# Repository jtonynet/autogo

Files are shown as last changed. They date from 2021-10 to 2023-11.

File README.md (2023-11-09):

### Raspberry Pi Autonomous Golang 1.16 robot

<!-- 
    Logo image generated by Bing IA: https://www.bing.com/images/create/
-->
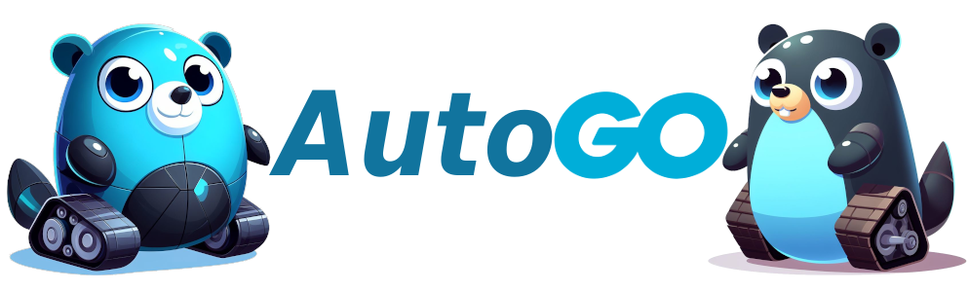
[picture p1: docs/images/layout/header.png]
CineCataloGO, Study RESTful APIs in Golang for cinema catalog management CineCataloGO

__Refactor para Go 1.21 em andamento*__

<br/>

[go Go](https://go.dev/) [Javascript](https://developer.mozilla.org/en-US/docs/Web/JavaScript) [NodeJS](https://nodejs.org/en) [Ubunto](https://ubuntu.com/) [DotEnv](https://github.com/spf13/viper) [GitHub](https://github.com/jtonynet) [Miro](https://miro.com/) [Fritzing](https://fritzing.org/)  [VsCode](https://code.visualstudio.com/) [Heroku](https://heroku.com) [MQTT](https://mqtt.org/) [RaspberryPi](https://www.raspberrypi.org/) [Arduino](https://www.arduino.cc/) 

 

<br/>

#### 🕸️ Minhas Redes:
     

---

Projeto em desenvolvimento com finalidade de estudo de uso de Golang com Robotica Básica e IOT (libs [Gobot](https://gobot.io/) e [Gocv](https://gocv.io/)), funcional na plataforma base (Raspberry 3b+/4b Rasbpian recente).

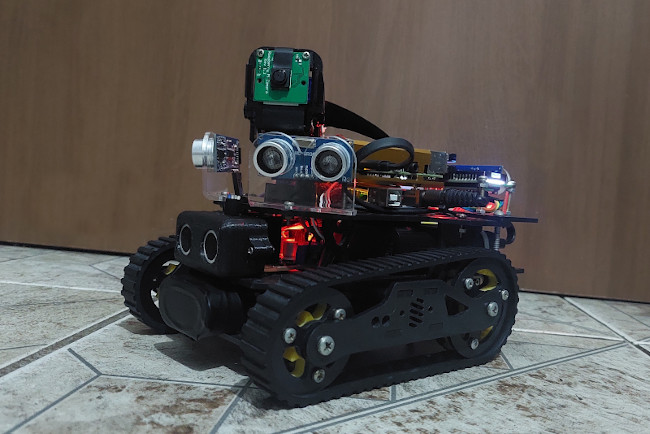
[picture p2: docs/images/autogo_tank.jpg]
versão atual montado


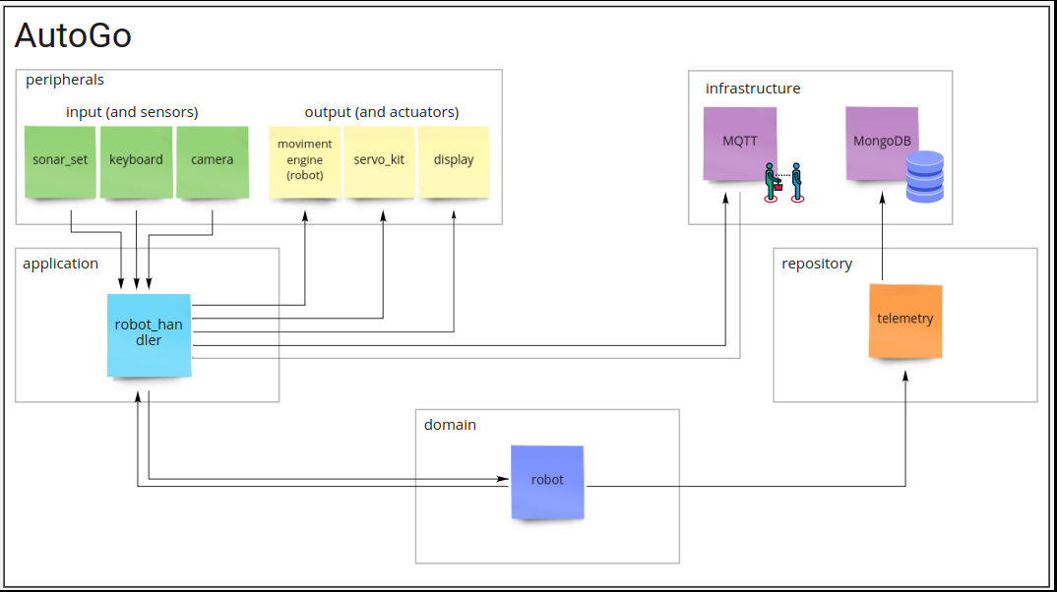
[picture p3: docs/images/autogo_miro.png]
arquitetura


Setup:
  1. Em uma plataforma raspberry que siga o esquema autoGo e seus [scripts auxiliares](./scripts/README.md), instalar o [pi-blaster](https://github.com/sarfata/pi-blaster)

  2. Rodar ´sudo raspi-config´ entrar em ´3 Interface Options´ para habilitar a interface de camera ´P1 Camera´ e o barramento ´P5 I2C´

  3. Rodar o comando para alterar pinagem i2c e habilitar todos pins para o gobot: `./autogo.sh`

  4. Gerando Binário com raspberry como device alvo: `GOARM=6 GOARCH=arm GOOS=linux go build main.go`

  5. Rode o Binário. Com um teclado conectado ao raspberry, teclas de seta movimentam o veiculo, teclas "a, w, s, d" movimentam os servos da camera. Stream de video, condução pela web (pagina cliente) e condução autônoma (via sensor de sonar e outros métodos) ainda serão implementados

Esquema autoGo
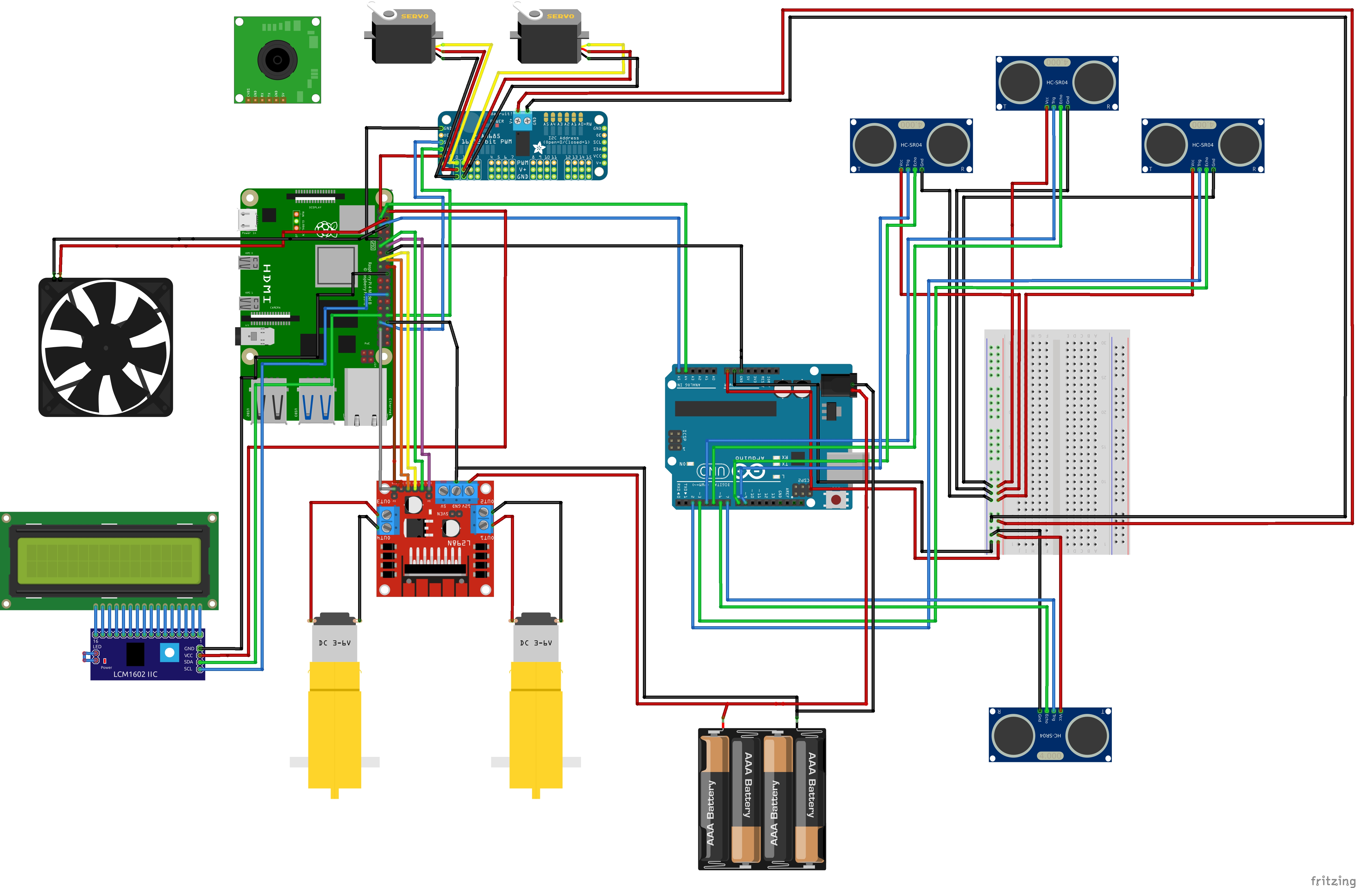
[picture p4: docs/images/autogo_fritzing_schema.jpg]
esquema


Setup Client:
  1. Configurar no arquivo .env o MessagerBroker com dados de uma conta MQTT. Broker [hive](https://www.hivemq.com/mqtt-cloud-broker/) gratuito sugerido
   
  2. Rodar `docker build --tag autogo-client-test .` e depois da imagem buildada rodar `docker run autogo-client-test`

  3. Validar mensagens de acordo com os recursos do autogo configurado na mesma fila com as mesmas envs `PROJECT_NAME` e `ROBOT_NAME`. Ter um client configurado no computador de testes é aconselhável, sugestão [mqtt-explorer](http://mqtt-explorer.com/)

Site Cliente e MQTT
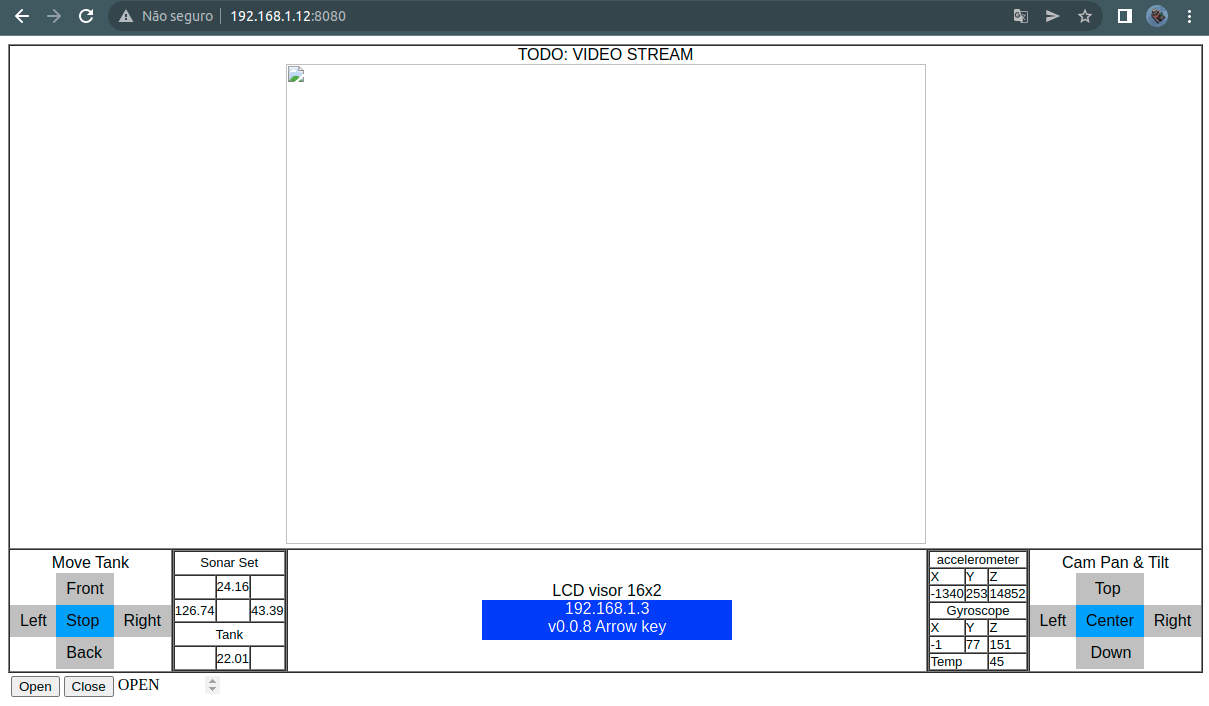
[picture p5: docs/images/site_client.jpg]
site cliente cliente


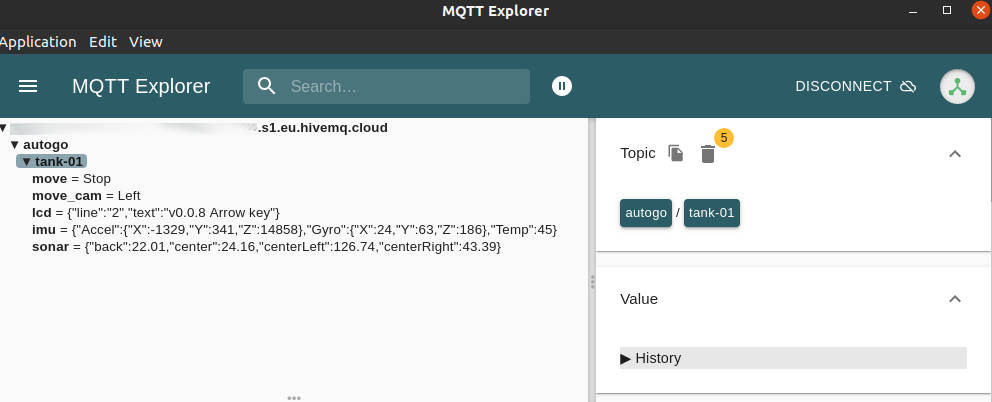
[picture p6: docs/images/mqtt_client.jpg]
app cliente cliente


Referências:
  - [Pq nao dockerizar o device?](https://ubuntu.com/blog/ros-docker)
  - [:::ROS Golang](https://ubuntu.com/blog/go-for-ros)
  - [Condução Autônoma IA com Intel 1](https://towardsdatascience.com/robot-tank-with-raspberry-pi-and-intel-neural-computer-stick-2-77263ca7a1c7)
  - [Go visão computacional](https://about.sourcegraph.com/go/gophercon-2018-computer-vision-using-go-and-opencv-3/)
  - [Raspberry com Gobot](https://gobot.io/documentation/platforms/raspi/)
  - [GPIO com Golang](https://pkg.go.dev/github.com/heupel/gobot/platforms/gpio#section-readme)
  - [Lib LCD i2c Golang](https://github.com/d2r2/go-hd44780)

-Próximas etapas:
  - ~~Refatoração na estrutura do código~~
  - ~~Condução Autônoma (Sonar set)~~
  - ~~Condução por Fila MQTT (e web Socket)~~
  - ~~Site Cliente para Condução~~
  - Dockerizar o site cliente e suas dependencias
  - Código mais aderente a boas práticas GO (interfaces, linter e demais melhorias)
  - SH e makefile para automatizar dependencias em instalação nova
  - SH update de goversion no raspbian
  - Testes e validação para outros SO, Ubunto Mate (raspberry 4b) e Ubunto Nvidia Jetson :)
  - Implantar ROS::: Golang

Componentes:
  - [Plataforma Rocket-tank](https://www.robocore.net/robotica-robocore/plataforma-robotica-rocket-tank)
  - [Kit de expansão Rocket-tank](https://www.robocore.net/item-mecanico/kit-de-expansao-rocket-tank)
  - [Suporte pan tilt](https://lista.mercadolivre.com.br/suporte-pan-tilt-arduino)
  - [PowerBank minimo 2,5 amperes](https://lista.mercadolivre.com.br/powerbank-mi#D[A:PowerBank%20mi])
  - [Bateria 7,2 V](https://lista.mercadolivre.com.br/bateria-leao-nimh-7.2#D[A:bateria%20leao%20nimh%207.2])
  - [Raspberry py ModelB 3 ou mais recente](https://lista.mercadolivre.com.br/raspberry-py-modelb-3)
  - [Case raspberry com fan](https://lista.mercadolivre.com.br/case-raspberry-pi-cooler-duplo-aluminio_OrderId_PRICE_NoIndex_True)
  - [Raspicam](https://www.robocore.net/acessorios-raspberry-pi/camera-para-raspberry-pi-rev-1-3)
  - [16 ch pwm](https://lista.mercadolivre.com.br/16-ch-pwm)
  - [2x servos motores 9g](https://lista.mercadolivre.com.br/servos-motores-9g#D[A:servos%20motores%209g])
  - [Ponte H l298n](https://lista.mercadolivre.com.br/raspiberry-cam)
  - [Display LCD 16x2 i2c](https://lista.mercadolivre.com.br/display-16x2-i2c#D[A:display%2016x2%20i2c])
  - [4x Sensores Sonar](https://lista.mercadolivre.com.br/arduino-sonar-sensores#D[A:arduino%20sonar%20sensores])
  - [Arduino UNO](https://lista.mercadolivre.com.br/arduino-uno#D[A:Arduino%20UNO])
  - [Mini teclado sem fio](https://lista.mercadolivre.com.br/mini-keyboard#D[A:mini%20keyboard])
  - [Parafusos e porcas M3 20mm e 12mm](https://lista.mercadolivre.com.br/parafusos-e-porcas-m3-20mm#D[A:Parafusos%20e%20porcas%20M3%2020mm])
  - [Conector p4 2.1 mm](https://lista.mercadolivre.com.br/conector-p4-2.1-mm#D[A:conector%20p4%202.1%20mm])
  - [MPU9250](https://lista.mercadolivre.com.br/mpu9250#D[A:MPU9250])
  - MiniProtoboard OU Tubos termo retrateis, Cabos, fita isolante, curiosidade vontade e disposição para nao se frustrar muito no processo (o que não raro, vai acontecer)

Criando novas Issues. A ideia é manter atualizado enquanto avanço em Golang e outros tópicos vinculados interessantes.

Existe uma versão do projeto em Python (Autobot), pretendo andar com ela em paralelo pois Python já possui soluções que serão portadas para o AutoGo.

Um estudo divertido.
Todos estamos tentando melhorar. ;)

primeiro teste

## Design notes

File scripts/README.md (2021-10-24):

Scripts e códigos auxiliares para rodar o AutoGo (migrar para outro projeto no futuro)

  1. Baixar o [arduino](https://www.arduino.cc/) e subir o sketch (arquivo) do SonarSet no Arduino uno utilizado no AutoGo (em próximas versões o sketch será em golang e não mais um INO)

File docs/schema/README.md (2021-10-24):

[Baixar o fritzing](https://fritzing.org/download/) Para ter acesso e poder alterar o esquema de pinagem utilizado no AutoGo

Componentes que podem faltar na instalacao base do fritzing e outros exemplos:

  -  [Adafruit (pca9685)](https://github.com/adafruit/Fritzing-Library)
  -  [HC-SR04](https://github.com/RafaGS/Fritzing/blob/master/HC-SR04.fzpz)
  -  [L298N](https://forum.fritzing.org/t/h-bridge-with-l298n-motor-driver/7711/2)
  -  [i2c-lcd](https://fritzing.org/projects/arduino-i2c-lcd-display)
  -  [Servo](https://fritzing.org/projects/scratchx-servo-motor)
  -  [Fan](https://fritzing.org/projects/greenhouse-2)

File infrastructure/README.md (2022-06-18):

###MQTT tbm deve ir para um SH... talvez esse faça sentido Dockerizar

- [Instalação MQTT](https://www.instructables.com/Installing-MQTT-BrokerMosquitto-on-Raspberry-Pi/)

- [Boas práticas MQTT Amazon](https://docs.aws.amazon.com/whitepapers/latest/designing-mqtt-topics-aws-iot-core/mqtt-design-best-practices.html) e [Boas práticas MQTT Gerais](https://github.com/mqtt/mqtt.org/wiki/SYS-Topics)

- [Ferramenta MQTT](https://mqtt-explorer.com/)

- [Página de testes](https://test.mosquitto.org/)

- [Notas de instalação e resolução de problemas](https://github.com/eclipse/mosquitto/issues/529)

cd ~/etc/apt/sources.list.d
sudo -i

```
sharatkanthi commented on Apr 16, 2018
This is because the web socket library is not installed. Try running

sudo apt-get install libwebsockets-dev

before running

sudo apt-get install mosquitto
```

- [Problema de duplicidade, tenta subir o server MQTT duas vezes na porta 1883][http://www.steves-internet-guide.com/mosquitto-broker/]
```
mosquitto -V
sudo service mosquitto stop
sudo systemctl stop mosquitto.service
fuser -k 1883/tcp
mosquitto -V
```

- Testando (com 3 janelas distintas)
```
mosquitto

mosquitto_sub -h 0.0.0.0 -p 1883 -t 'autogo-test'

mosquitto_pub -h 0.0.0.0 -p 1883 -t 'autogo-test' -m 'test 3'
```

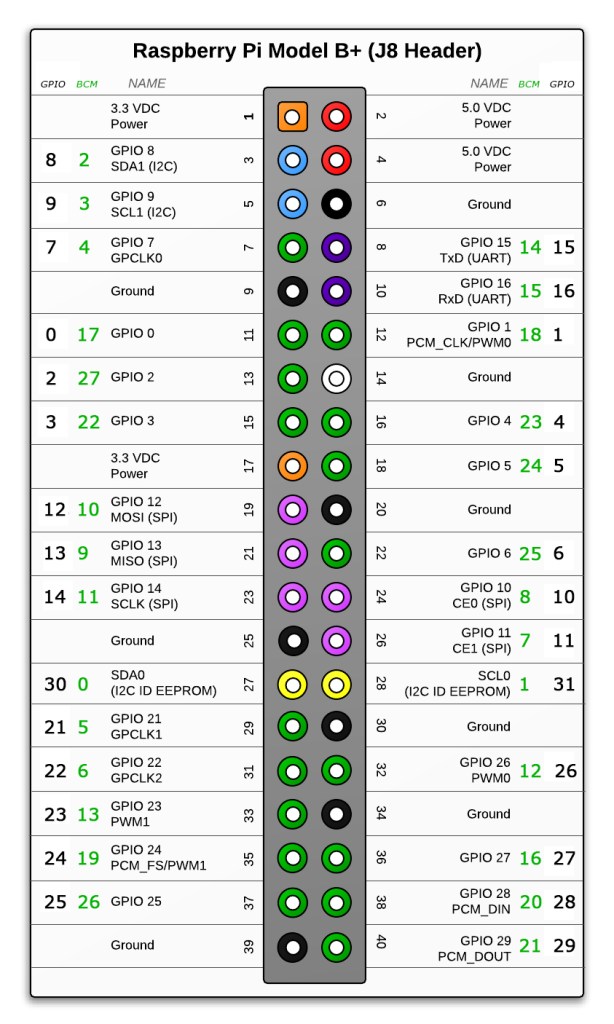
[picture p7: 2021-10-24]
docs/images/raspi_pins.jpg

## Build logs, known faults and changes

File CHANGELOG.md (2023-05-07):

# Changelog

All notable changes to this project will be documented in this file.

The format is based on [Keep a Changelog](https://keepachangelog.com/en/1.0.0/),
and this project adheres to [Semantic Versioning](https://semver.org/spec/v2.0.0.html).

## [Unreleased]
### Added 

## [0.0.8] - 2022-06-18
### Changed 
- Usando fila gratuita [hive](https://www.hivemq.com/mqtt-cloud-broker/) para mensageria MQTT ao invés de Mosquitto local
- Peripherals inputs e outputs renomeado para sensor e actuators
- Mais alguns arquivos renomeados para melhorar a clareza do código
  
### Added
- Site cliente adicionado com receita docker, funcional via MQTT e Websocket
- Comunicação entre site cliente e autogo implementada
- Sensor IMU "MPU9250" adicionado em actuators e domain, enviando dados para fila

## [0.0.7] - 2021-11-11

### Added 
- [Instalação Mosquito MQTT](https://www.instructables.com/Installing-MQTT-BrokerMosquitto-on-Raspberry-Pi/) mais um processo para automatizar (esse talvez possa deixar em docker)
- Criada Infrastructure MQTT seguindo [EMQ](https://www.emqx.com/en/blog/how-to-use-mqtt-in-golang), [AWS](https://docs.aws.amazon.com/pt_br/whitepapers/latest/designing-mqtt-topics-aws-iot-core/mqtt-design-best-practices.html) e [Hive MQTT](https://www-hivemq-com.translate.goog/blog/mqtt-essentials-part-4-mqtt-publish-subscribe-unsubscribe/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)
- Domain robotAggregator refactor para Responsabilidade unica de metodos
- Domain para LCD e Sonar com logica de mensageria
- EnvVars e mais alguns outros fixes

## [0.0.6] - 2021-11-02

### Added

- [Instalação Gocv](https://gocv.io/getting-started/linux/)
- Adicionando uso simples de [Gocv](https://github.com/willmendil/golang_tutorials/blob/master/tutorial_1/main.go)/OpenCv para video stream
- Display LCD na linha 1 exibe ip e porta de rede da camera caso online)
- Env vars de uso da camera
- Acertos no keyboard e Wrapper de keyevent (ainda não está 100%)

## [0.0.5] - 2021-10-30

### Added

- Perifericos (sensors/actuators) podem ser habilitados por envVars
    - Montagem minima apenas com motores (ou qualquer outra combinação) agora pode ser configurada nas envs
    - Sem a necessidade de montar o projeto completo. Habilite apenas os recursos que vai plugar no esquema
- Adotando arquitetura hexagonal, desacoplando lib goBot com wrappers (problemas de desacoplamento com o keyboard)
- Série de pequenas correções por conta de conflitos (ainda existem dois repos, preciso remover do 'MatrixReality')

## [0.0.4] - 2021-10-24

### Added

- Usando viper para envVars
- Segregando envVars por modulos
- Corrigindo entradas do README

## [0.0.3] - 2021-10-23

### Added

- Comportamento de parada ao detectar obstáculo no sonar frontal do centro
- Inicio da documentação (CHANGELOG e melhorias no README.md, com mais commits do que gostaria de ter feito :| )
- Adicionado aos docs o esquema fritzing e arquivos de apoio a construção
- Adicionada pasta de scripts com o arquivo .ino do SonarSet

## [0.0.2] - 2021-10-23

### Added

- Mudança de repositório. Saindo do repo de estudos
- Refactor para arquitetura de periféricos, usando wrapper para gobot na maioria de sensorss/outputs
- ['Driver' para Arduino](https://github.com/hybridgroup/gobot/blob/a8f33b2fc012951104857c485e85b35bf5c4cb9d/drivers/i2c/README.md)

[0.0.8]: https://github.com/jtonynet/autogo/compare/v0.0.7...v0.0.8
[0.0.7]: https://github.com/jtonynet/autogo/compare/v0.0.6...v0.0.7
[0.0.6]: https://github.com/jtonynet/autogo/compare/v0.0.5...v0.0.6
[0.0.5]: https://github.com/jtonynet/autogo/compare/v0.0.4...v0.0.5
[0.0.4]: https://github.com/jtonynet/autogo/compare/v0.0.3...v0.0.4
[0.0.3]: https://github.com/jtonynet/autogo/compare/v0.0.2...v0.0.3
[0.0.2]: https://github.com/jtonynet/autogo/releases/tag/v0.0.2

cd Documents/tools
./ngrok http -bind-tls=true 9001
./ngrok http -bind-tls=true 8081

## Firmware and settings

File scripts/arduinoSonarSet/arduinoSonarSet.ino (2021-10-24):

//Programa: Coleta dados de um poll de sensores Ultrassonico 
//HC-SR04 e comunica via I2C Arduino e Raspberry Pi (permite 4 sensores)

#include <Wire.h>
#include <Ultrasonic.h>

//Define os pinos para o trigger e echo
#define pino_trigger_front 4
#define pino_echo_front 5

#define pino_trigger_front_right 2
#define pino_echo_front_right 3

#define pino_trigger_back 7
#define pino_echo_back 6

#define pino_trigger_front_left 9
#define pino_echo_front_left 8

//Inicializa o sensor nos pinos definidos acima
Ultrasonic ultrasonic_front(pino_trigger_front, pino_echo_front);
Ultrasonic ultrasonic_front_right(pino_trigger_front_right, pino_echo_front_right);
Ultrasonic ultrasonic_back(pino_trigger_back, pino_echo_back);
Ultrasonic ultrasonic_front_left(pino_trigger_front_left, pino_echo_front_left);

char resultBuffer[36];
char col_c[7];
char col_r[7];
char col_b[7];
char col_l[7];
char value_c[4];
char value_r[4];
char value_b[4];
char value_l[4];

void setup()
{
  Serial.begin(9600);
  Wire.begin(0x18);
  Wire.onRequest(requestEvent);
}

void requestEvent()
{
  String result = "";
  float max_limit = 999.99;

  //Its dont work, i use string concat fix solution
  //sprintf(str, "%s,%s,%s,%s,", col_c, col_r, col_b, col_l);
  
  float cmMsec_front;
  long microsec_front = ultrasonic_front.timing();
  cmMsec_front = ultrasonic_front.convert(microsec_front, Ultrasonic::CM);

  if(cmMsec_front > max_limit){
    cmMsec_front = max_limit;
  }
  
  dtostrf(cmMsec_front,4,2, value_c);
  sprintf(col_c, "%s,", value_c);
  result.concat(col_c);

  float cmMsec_front_right;
  long microsec_front_right = ultrasonic_front_right.timing();
  cmMsec_front_right = ultrasonic_front_right.convert(microsec_front_right, Ultrasonic::CM);

  if(cmMsec_front_right > max_limit){
    cmMsec_front_right = max_limit;
  }
  
  dtostrf(cmMsec_front_right,4,2, value_r);
  sprintf(col_r, "%s,", value_r);
  result.concat(col_r);

  float cmMsec_back;
  long microsec_back = ultrasonic_back.timing();
  cmMsec_back = ultrasonic_back.convert(microsec_back, Ultrasonic::CM);

  if(cmMsec_back > max_limit){
    cmMsec_back = max_limit;
  }
  
  dtostrf(cmMsec_back,4,2, value_b);
  sprintf(col_b, "%s,", value_b);
  result.concat(col_b);

  float cmMsec_front_left;
  long microsec_front_left = ultrasonic_front_left.timing();
  cmMsec_front_left = ultrasonic_front_left.convert(microsec_front_left, Ultrasonic::CM);

  if(cmMsec_front_left > max_limit){
    cmMsec_front_left = max_limit;
  }
  
  dtostrf(cmMsec_front_left,4,2, value_l);
  sprintf(col_l, "%s,", value_l);
  result.concat(col_l);
  
  //        center,cRight,back  ,cLeft 
  //result="000.00,000.00,000.00,000.00,";
  //result="999.99,999.99,999.99,999.99,";
  
  result.toCharArray(resultBuffer, 36);
  
  Serial.println(result);
  Serial.println(" ");
  Wire.write(resultBuffer);
}

void loop()
{
  delay(1000);
}

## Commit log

2021-10-23 adding sonar set like 'arduino driver'
2021-10-23 sonar sensor on keyboard handlers stop car when detects collision routes
2021-10-23 add sonar worker and documents folder
    [autogo-fritzing.fzz]
2021-10-23 rename documents folder
    [autogo-fritzing.fzz]
2021-10-24 add .env-sample and config module
2021-10-27 enable peripherals sensors and actuators via env vars
2021-11-02 add gocv and peripheral input camera stream and fix keyboard application dependency
2021-11-02 New camera envvars, bump version and some fixes
2021-11-26 domain directories refactor and add sonar self control
2022-07-10 fix actuators/sensors rename
